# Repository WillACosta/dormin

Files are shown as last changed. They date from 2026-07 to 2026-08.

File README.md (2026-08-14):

## Dormin Split Keyboard

> 3×6 (+2 outer-pinky) Split Keyboard · 3 Thumb Keys · All 1U · MX Compatible

Dormin is a 42 — 36 keys split keyboard, inspired by some awesome keyboards that I've used and loved. The main goal is to create a customizable keyboard with optional features, but still as minimal as possible regarding the design.

### Must have specs

- Wireless Ble.
- Ultra low-profile build (<= 7mm).
- Low-profile switches and keycaps.
- Compatible with MX-Standard and the Gateron KS33/3.0 Low-Profile switches & Choc V2.
- Huge battery life (1200mAh).
- Minimalist and industrial design.
- Aluminum case and plate.
- 4 different layouts trough breakaway parts.
- Split and "Unibody" layouts (Using Pogo pins)
- MX-Spacing
- Status LEDs

**Optional**

- EC12 Rotatory Encoder
- SD OLED screen or Nice!View

## Layout Overview

The Dormin is a **40-key split keyboard** (20 keys per half) with a column-staggered matrix and a splayed thumb cluster.

| Zone | Columns | Rows | Keys/half | Notes |
|---|---|---|---|---|
| Matrix | 6 (outer → inner) | 3 (bottom, home, top) | 17 | Outer column skips bottom row (2 keys only) |
| Thumb | 3 (inner, home, outer) | 1 | 3 | Splayed arc, anchored below index |
| **Total** | | | **20** | **40 keys full board** |

### Column Stagger Profile

```
         outer  pinky  ring   middle  index  inner
stagger:   —    +u/2   +u/4   +u/4   −u/4   −u/4
mm:        0    +9.525 +4.763 +4.763 −4.763 −4.763
```

```
                    ┌──┐┌──┐
               ┌──┐ │  ││  │ ┌──┐
          ┌──┐ │  │ │Mi││Mi│ │  │ ┌──┐
     ┌──┐ │  │ │Ri││dd││dd│ │In│ │  │
     │  │ │Pi│ │ng││le││le│ │ne│ │  │
     │Ou│ │nk│ │  ││  ││  │ │r │ │  │
     │te│ │y │ │  ││  ││  │ │  │ │  │
     │r │ │  │ │  ││  ││  │ │  │ │  │
     └──┘ │  │ │  │└──┘└──┘ │  │ │  │
          └──┘ └──┘          └──┘ └──┘
                    ┌──┐
               ┌──┐│  │┌──┐
               │Th ││Th││Th│
               │ 3 ││ 2││ 1│
               └──┘└──┘└──┘
```

### Thumb Cluster Geometry

| Key | Splay | Spread | Stagger | Effective rotation |
|-----|---|---|---|---|
| thumb_inner | 0° | u (19.05mm) | 0mm | 0° |
| thumb_home | −15° | u+2.5 (21.55mm) | −2.7mm | −15° |
| thumb_outer | −14° | u+2.5 (21.55mm) | −2.5mm | −29° |

The thumb cluster anchors at `matrix_index_bottom` with a `[-0.1u, -1.30u]` offset, placing it slightly left and well below the index column — a natural resting position for the thumb.

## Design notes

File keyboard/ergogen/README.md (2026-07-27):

# Ergogen Layout Configuration

Ergogen is used to generate key switch positions, panel outlines, and KiCad PCB drafts.

## Generating Ergogen Files

To generate the PCB layout (`.kicad_pcb`) and outline assets using Ergogen:

1. **Run Ergogen CLI**:
   ```bash
   npx ergogen keyboard/ergogen -o keyboard/generated
   ```

2. **Generated Output (`keyboard/generated/`)**:
   - `keyboard/generated/pcbs/dormin.kicad_pcb`: Contains the KiCad PCB with switch footprints (`SW1` to `SW42`) using standard MX spacing and Edge.Cuts outlines.
   - `keyboard/generated/outlines/`: Contains DXF/SVG outline assets for switch plates and case panels.

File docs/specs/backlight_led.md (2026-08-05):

# Dormin Keyboard — White Backlight System

## Overview

Dormin uses a **single-zone white LED backlight** inspired by Apple's Magic Keyboard and MacBook keyboards. The objective is to provide a subtle, elegant, and battery-efficient backlight while keeping the hardware simple, inexpensive, and easy to manufacture using JLCPCB SMT Assembly.

Each keyboard half contains:

- One Seeed Studio XIAO nRF52840 Plus
- One AO3400A N-Channel MOSFET
- One warm white LED underneath each switch
- One current-limiting resistor per LED
- Dedicated LED power rail (`LED_VCC`)
- PWM brightness control

The entire backlight is controlled as a **single lighting zone**, allowing global brightness adjustment through PWM without requiring a dedicated LED driver.

### Why No LED Driver?

Dormin Rev. A intentionally avoids dedicated LED driver ICs (IS31FL37xx family).

Instead, all LEDs are switched simultaneously using a single PWM-controlled MOSFET.

#### Advantages

- Only one GPIO required
- Very small BOM
- Extremely simple schematic
- Easy PCB routing
- Excellent battery life
- Minimal firmware complexity
- Fully supported by ZMK PWM

#### Trade-offs

Supported:

- ✅ Backlight ON/OFF
- ✅ Global brightness control
- ✅ PWM dimming
- ✅ Fade in / Fade out
- ✅ Auto-off after inactivity

Not supported:

- ❌ Per-key brightness
- ❌ Reactive typing
- ❌ Ripple animations
- ❌ RGB effects
- ❌ Multiple lighting zones

# Power Architecture

Unlike the MCU and OLED, the backlight **does not use the XIAO's regulated 3.3 V output**.

Instead, the LEDs are powered directly from the battery.

Advantages:

- Lower regulator load
- Better battery efficiency
- Lower regulator temperature
- Higher available current
- Easier future expansion

The battery voltage is distributed into two independent branches:

- XIAO VBAT input
- LED_VCC (Backlight power rail)

---

# Electrical Architecture

```mermaid
flowchart LR

    BAT["LiPo Battery"]

    BRANCH((Power Junction))

    MCU["XIAO nRF52840 Plus"]

    PWM["LED_PWM GPIO"]

    RG["100R"]

    MOS["AO3400A<br/>N-MOSFET"]

    RPD["10K"]

    GND["GND"]

    CAP1["10uF"]
    CAP2["100nF"]

    subgraph BACKLIGHT["White Backlight"]

        R1["1K"]
        LED1["LED"]

        R2["1K"]
        LED2["LED"]

        RN["1K"]
        LEDN["LED ..."]

    end

    BAT --> BRANCH

    BRANCH --> MCU

    BRANCH --> LED_VCC["LED_VCC"]

    LED_VCC --> CAP1
    LED_VCC --> CAP2

    CAP1 --> GND
    CAP2 --> GND

    MCU --> PWM

    PWM --> RG

    RG --> MOS

    RPD --> GND
    RPD --> MOS

    LED_VCC --> R1 --> LED1 --> MOS
    LED_VCC --> R2 --> LED2 --> MOS
    LED_VCC --> RN --> LEDN --> MOS

    MOS --> GND
```

---

# Bill of Materials (BOM)

| Component | Value / Part Number | KiCad Symbol | KiCad Footprint | JLCPCB Assembly | Remarks | PCB / Schematic Notes |
|---|---|---|---|---|---|---|
| MCU | Seeed Studio XIAO nRF52840 Plus | `Seeed Studio XIAO nRF52840 Plus` *(Seeed official library)* | `Module:Seeed_XIAO_nRF52840_Plus` | ❌ Module | Main controller | One module per keyboard half |
| White LED | 0603 Warm White LED (≈4000–4500K) | `Device:LED` | `LED_SMD:LED_0603_1608Metric` | ✅ Yes | White backlight | One LED per switch |
| LED Current Limiting Resistor | **1K ±1%** | `Device:R` | `Resistor_SMD:R_0603_1608Metric` | ✅ Yes | Current limiting | One resistor per LED (VBAT-powered design) |
| Gate Resistor | **100R ±1%** | `Device:R` | `Resistor_SMD:R_0603_1608Metric` | ✅ Yes | Limits MOSFET gate charging current | Place close to MOSFET gate |
| Gate Pull-down Resistor | **10K ±1%** | `Device:R` | `Resistor_SMD:R_0603_1608Metric` | ✅ Yes | Keeps MOSFET OFF during boot | Gate → GND |
| MOSFET | AO3400A | `Device:Q_NMOS_GSD` | `Package_TO_SOT_SMD:SOT-23` | ✅ Yes | Low-side PWM switch | One per keyboard half |
| Bulk Capacitor | **10uF X5R/X7R ≥6.3V** | `Device:C` | `Capacitor_SMD:C_0603_1608Metric` *(0805 also acceptable)* | ✅ Yes | Bulk decoupling | Between `LED_VCC` and GND |
| High-Frequency Capacitor | **100nF X7R** | `Device:C` | `Capacitor_SMD:C_0603_1608Metric` | ✅ Yes | PWM noise filtering | Place next to the 10uF capacitor |
| Test Point *(Optional)* | Test Pad | `Connector:TestPoint` | `TestPoint:TestPoint_Pad_D1.0mm` | Optional | Debugging | Recommended for `LED_VCC` (optionally `LED_PWM`) |

---

# PCB Design Guidelines

## LED Placement

- One LED centered underneath each switch.
- Keep the LED as close as possible to the switch opening.
- Maintain consistent orientation across the PCB.

## MOSFET Placement

Place the AO3400A:

- Close to the XIAO module
- Close to the `LED_PWM` GPIO
- Close to the main `LED_SWITCH` return path

This minimizes PWM trace length and switching noise.

## Capacitor Placement

Place the **10uF** and **100nF** capacitors:

- Immediately after the `LED_VCC` power entry
- Close together
- Before the LED power distribution begins

## Power Routing

Recommended trace widths:

| Signal | Recommended Width |
|---|---:|
| BAT+ | 1.0 mm |
| LED_VCC | 0.5–1.0 mm |
| LED_SWITCH | 0.5–1.0 mm |
| LED_PWM | 0.20–0.25 mm |

---

# Firmware Features

Supported by the current hardware:

- Backlight ON/OFF
- Brightness adjustment
- PWM dimming
- Fade effects
- Auto-off after timeout
- Battery-saving modes

Future firmware may support:

- Ambient light sensor
- Automatic brightness
- Sleep fade animation

without requiring any hardware changes.

---

# Future Expansion

The current architecture intentionally leaves room for future revisions.

Possible upgrades include:

- Ferrite bead between `BAT+` and `LED_VCC`
- Current sensing
- Polyfuse protection
- Dedicated LED regulator
- I²C LED driver
- Multiple lighting zones

None of these upgrades require changing the LED placement or mechanical design.

---

# Final Design Summary

The Dormin backlight system prioritizes simplicity, efficiency, and longevity over visual effects.

The final architecture consists of:

- White-only backlight
- Single lighting zone
- PWM-controlled AO3400A MOSFET
- One resistor per LED
- LEDs powered directly from the battery (`VBAT`)
- Dedicated `LED_VCC` power rail
- 10uF + 100nF local decoupling
- No LED driver
- Fully compatible with ZMK
- Optimized for wireless battery-powered operation
- Easy to manufacture with JLCPCB SMT Assembly

This design closely follows the philosophy used in premium commercial keyboards: minimal hardware complexity, excellent battery life, and a clean, understated lighting experience.

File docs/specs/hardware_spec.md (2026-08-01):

## Hardware Definitions

This document describes the hardware decisions and choices for the Dormin Keyboard.

## Must Have

- Usage of "Panelized Non-Reversible" PCB (costs saving and easy routing).
- Seeed Studio XIAO nRF52840 Plus (20 GPIO).
- Optional components: OLED SSD1306 or Nice!View ; EC12 Rotatory Encoder.

## WIP

- RGB LEDs for status indicador ([WIP](./led_status_system.md)).
- Add tiny magnets on the side to "lock" the halves and use "unibody-like" (alternative to the pogo-pins).
- Add tiny magnets on the bottom to secure halves during transport and easy travel.

## Research

These are some ideas, but are not yet solid for implementation. Needs deep research.

- Pogo Pins support for charging the peripherel (while central is connected on power).
- NFC for wireless charging

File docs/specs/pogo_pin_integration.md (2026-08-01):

```mermaid
flowchart LR
    subgraph Left["Main / Left Keyboard Half - Schema v2 (Diode Added)"]
        L_XIAO["XIAO nRF52840"]
        L_BAT("LiPo Battery")
        L_DIODE["Schottky Diode (e.g. B5819WS)"]
        L_POGO["4-Pin Pogo Connector"]
        L_R1["330Ω Resistor"]
        L_R2["330Ω Resistor"]

        L_XIAO ---|BAT+| L_BAT
        L_XIAO ---|5V / VBUS| L_DIODE
        L_DIODE ---|Cathode → Pin 1| L_POGO
        L_XIAO ---|GND → Pin 2| L_POGO

        L_XIAO ---|GPIO TX| L_R1
        L_R1 ---|Pin 3| L_POGO

        L_XIAO ---|GPIO RX| L_R2
        L_R2 ---|Pin 4| L_POGO
    end

    subgraph Right["Peripheral / Right Keyboard Half"]
        R_POGO["4-Pad Target Contact"]
        R_XIAO["XIAO nRF52840"]
        R_BAT("LiPo Battery")
        R_R1["330Ω Resistor"]
        R_R2["330Ω Resistor"]

        R_POGO ---|Pad 1 → 5V / VBUS| R_XIAO
        R_POGO ---|Pad 2 → GND| R_XIAO

        R_POGO ---|Pad 3| R_R1
        R_R1 ---|GPIO TX| R_XIAO

        R_POGO ---|Pad 4| R_R2
        R_R2 ---|GPIO RX| R_XIAO

        R_XIAO ---|BAT+| R_BAT
    end

    L_POGO ===|Physical Magnetic Mating| R_POGO
```

```mermaid
flowchart LR

%% =====================================================================
%% LEFT HALF
%% =====================================================================

subgraph LEFT["Main / Left Half"]

    USB["USB_VBUS"]
    PF["Polyfuse (Optional)"]
    D["Schottky Diode"]
    TVS5L["5V TVS"]

    MCU_L["XIAO nRF52840 Plus"]
    BAT_L["LiPo Battery"]

    TVSD_L["2-Channel TVS"]
    R1["33Ω"]
    R2["33Ω"]

    POGO_L["4-Pin Pogo Connector"]

    BAT_L <-->|BAT+/BAT-| MCU_L

    USB --> PF
    PF --> D
    D --> POGO_L

    POGO_L --- TVS5L
    TVS5L --> GNDL["GND"]

    MCU_L --> R1
    R1 --> TVSD_L
    TVSD_L --> POGO_L

    MCU_L --> R2
    R2 --> TVSD_L

    MCU_L --- GNDL
    GNDL --> POGO_L

end

%% =====================================================================
%% RIGHT HALF
%% =====================================================================

subgraph RIGHT["Peripheral / Right Half"]

    POGO_R["4-Pin Target Pads"]

    TVS5R["5V TVS"]
    TVSD_R["2-Channel TVS"]

    R3["33Ω"]
    R4["33Ω"]

    MCU_R["XIAO nRF52840 Plus"]
    BAT_R["LiPo Battery"]

    GNDR["GND"]

    BAT_R <-->|BAT+/BAT-| MCU_R

    POGO_R --> MCU_R

    POGO_R --- TVS5R
    TVS5R --> GNDR

    POGO_R --> TVSD_R
    TVSD_R --> R3
    R3 --> MCU_R

    TVSD_R --> R4
    R4 --> MCU_R

    POGO_R --> GNDR
    MCU_R --- GNDR

end

%% =====================================================================
%% MECHANICAL CONNECTION
%% =====================================================================

POGO_L ===|"Magnetic Pogo Interface"| POGO_R
```

## BOM

| Function | Recommended Part | Package | KiCad Footprint | Placement Rule | Routing Rule | Notes |
| --- | --- | --- | --- | --- | --- | --- |
| **Magnetic Pogo Connector** | Xinyangze **YZP0048-20048-04025-03** _(or equivalent 4-pin connector)_ | Vendor-specific | **Custom footprint** | **On the PCB edge**, aligned with the enclosure and magnets. | Keep `POGO_VBUS`, `POGO_GND`, `POGO_LINK_IO1`, and `POGO_LINK_IO2` as short as practical leaving the connector. | Verify mechanical clearance using the STEP model before manufacturing. |
| **Reverse Current Protection** | **B5819WS** | SOD-323 / SOD-123W _(manufacturer dependent)_ | `Diode_SMD:D_SOD-323` or matching package | **Near the USB/XIAO power input**, **not** near the pogo connector. | Route `USB_VBUS → Polyfuse → Schottky → POGO_VBUS`. | Prevents power from the pogo connector or battery from backfeeding into the USB supply. |
| **Overcurrent Protection (Optional)** | Polyfuse ~500 mA Hold _(e.g. 0ZCJ0050AF2E)_ | 1206 | `Fuse:Fuse_1206_3216Metric` | Immediately after the USB power source. | Place before the Schottky diode. | Optional, but recommended for a premium design to protect against shorts on the pogo interface. |
| **VBUS ESD Protection** | **SMF5.0A** | DO-219AB (SMF) | `Diode_SMD:D_SMF` | **As close as possible to the pogo connector.** | Connect **directly between `POGO_VBUS` and `GND`**. Use a **very short trace** and **dedicated GND via** beside the device. | First line of defense against ESD and transient surges on the charging pin. |
| **GPIO ESD Protection** | **TPD2E2U06DCKR** | SC70-3 (DCK) | `Package_TO_SOT_SMD:SOT-353_SC-70-3` | **Immediately beside the pogo connector.** | Signal flow should be: **Pogo → TVS → 33 Ω → MCU**. Connect GND with a **dedicated via** next to the GND pin. | Protects the exposed communication lines (`POGO_LINK_IO1`, `POGO_LINK_IO2`) from ESD. |
| **Series Resistors** | **33 Ω ±1%** | 0402 or 0603 | `Resistor_SMD:R_0402_1005Metric` _(or 0603)_ | **Near the MCU**, not the connector. | One resistor per communication line, placed **after the TVS** and **before the MCU GPIO**. | Improves signal integrity and limits transient current into the MCU. |

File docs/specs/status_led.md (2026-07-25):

## LED status indicators spec

This document shortly explain the definitions for the LED status indicators for the Dormin keyboard. Here are some approaches that I found on the community.

## Requirements

- Minimalist and discret design: LEDs are invisible when off.
- 3 individual RGB lights (each side).
- **Statuses**: Bluetooth Profiles, Battery, and Split link.

## Addressable RGB LEDs using SK6812 Mini-E

- LED Strip:SK6812 addressable LEDs (1-4 LEDs recommended)
- Power: 5V preferred (3.3V compatible), appropriate current capacity
- Data Connection: Single GPIO pin connected to strip's DI (Data In)
- SPI Interface: Available SPI peripheral (uses MOSI pin for data)

> Addressable LED implementations here on [hitsmaxft/zmk-rgbled-widget](https://github.com/hitsmaxft/zmk-rgbled-widget#adding-support-in-custom-boardsshields).

### LED status behaviors

Minimalist and easy-to-remember colors (Nuphy inspired).

**Connection**

🔵🔵🔵 = [Solid] (Left) Host connected
🔵🔵🔵 = [Breathing] (Left) Host disconnected
🔵🔵🔵 = [Blinking] (Left) Advertising

🔵🔵🔵 = [Solid] (Right) Split Linked
🔵🔵🔵 = [Breathing] (Right) Split disconnected

⚪⚪⚪ = [Solid] (Left) USB connected

**Battery**

🟢🟢🟢 = [Solid] (Left/Right) 80 - 100%
🟡🟡⚫ = [Solid] (Left/Right) 40 - 79%
🔴⚫⚫ = [Solid] (Left/Right) < 40%

🟢🟢🟢 = [Breathing] (Left/Right) Charging

**Layers**

Base = None
Symbol = None
Number = None
Media = 🔵 (Cyan)
Dev = None
Extra = 🟣

LEDs are activated in two moments:

- On boot it shows connection state and battery level, a solid color for 2s then turn off;
- On demand by using specific combos;

When not in use they are turned off to energy saving purpose.

## ARGB and LP5012 LED Driver

The LP driver allows fully controlled RGB lights with the `SDA` and `SCL` GPIOs, using the I2C protocol, as it's shared it can run more than one peripheral on the same NET. The LP enable the following:

- Fully smooth controlled animations
- Ultra Low power
- Don't need dedicated GPIO (Same NET as screens)

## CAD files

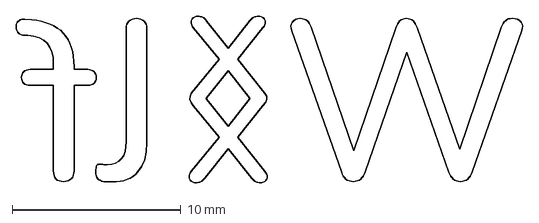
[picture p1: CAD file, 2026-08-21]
docs/assets/the_wolf_logo_full.dxf
30.1 x 9.87 mm

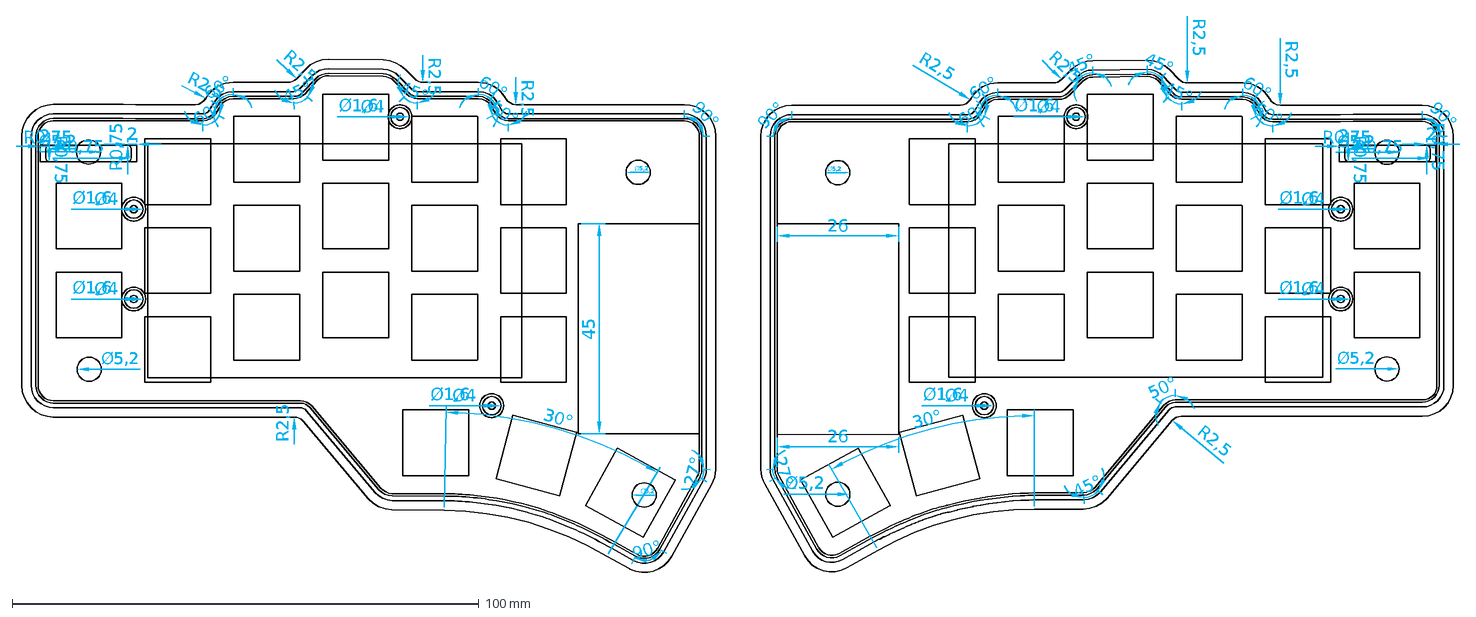
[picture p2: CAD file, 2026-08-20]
keyboard/case/projeccts/case_sketch.dxf
Ø5,2
45
2
26
R0,75
R2,5
Ø1,6
Ø4
27°
90°
45°
50°
60°
30°

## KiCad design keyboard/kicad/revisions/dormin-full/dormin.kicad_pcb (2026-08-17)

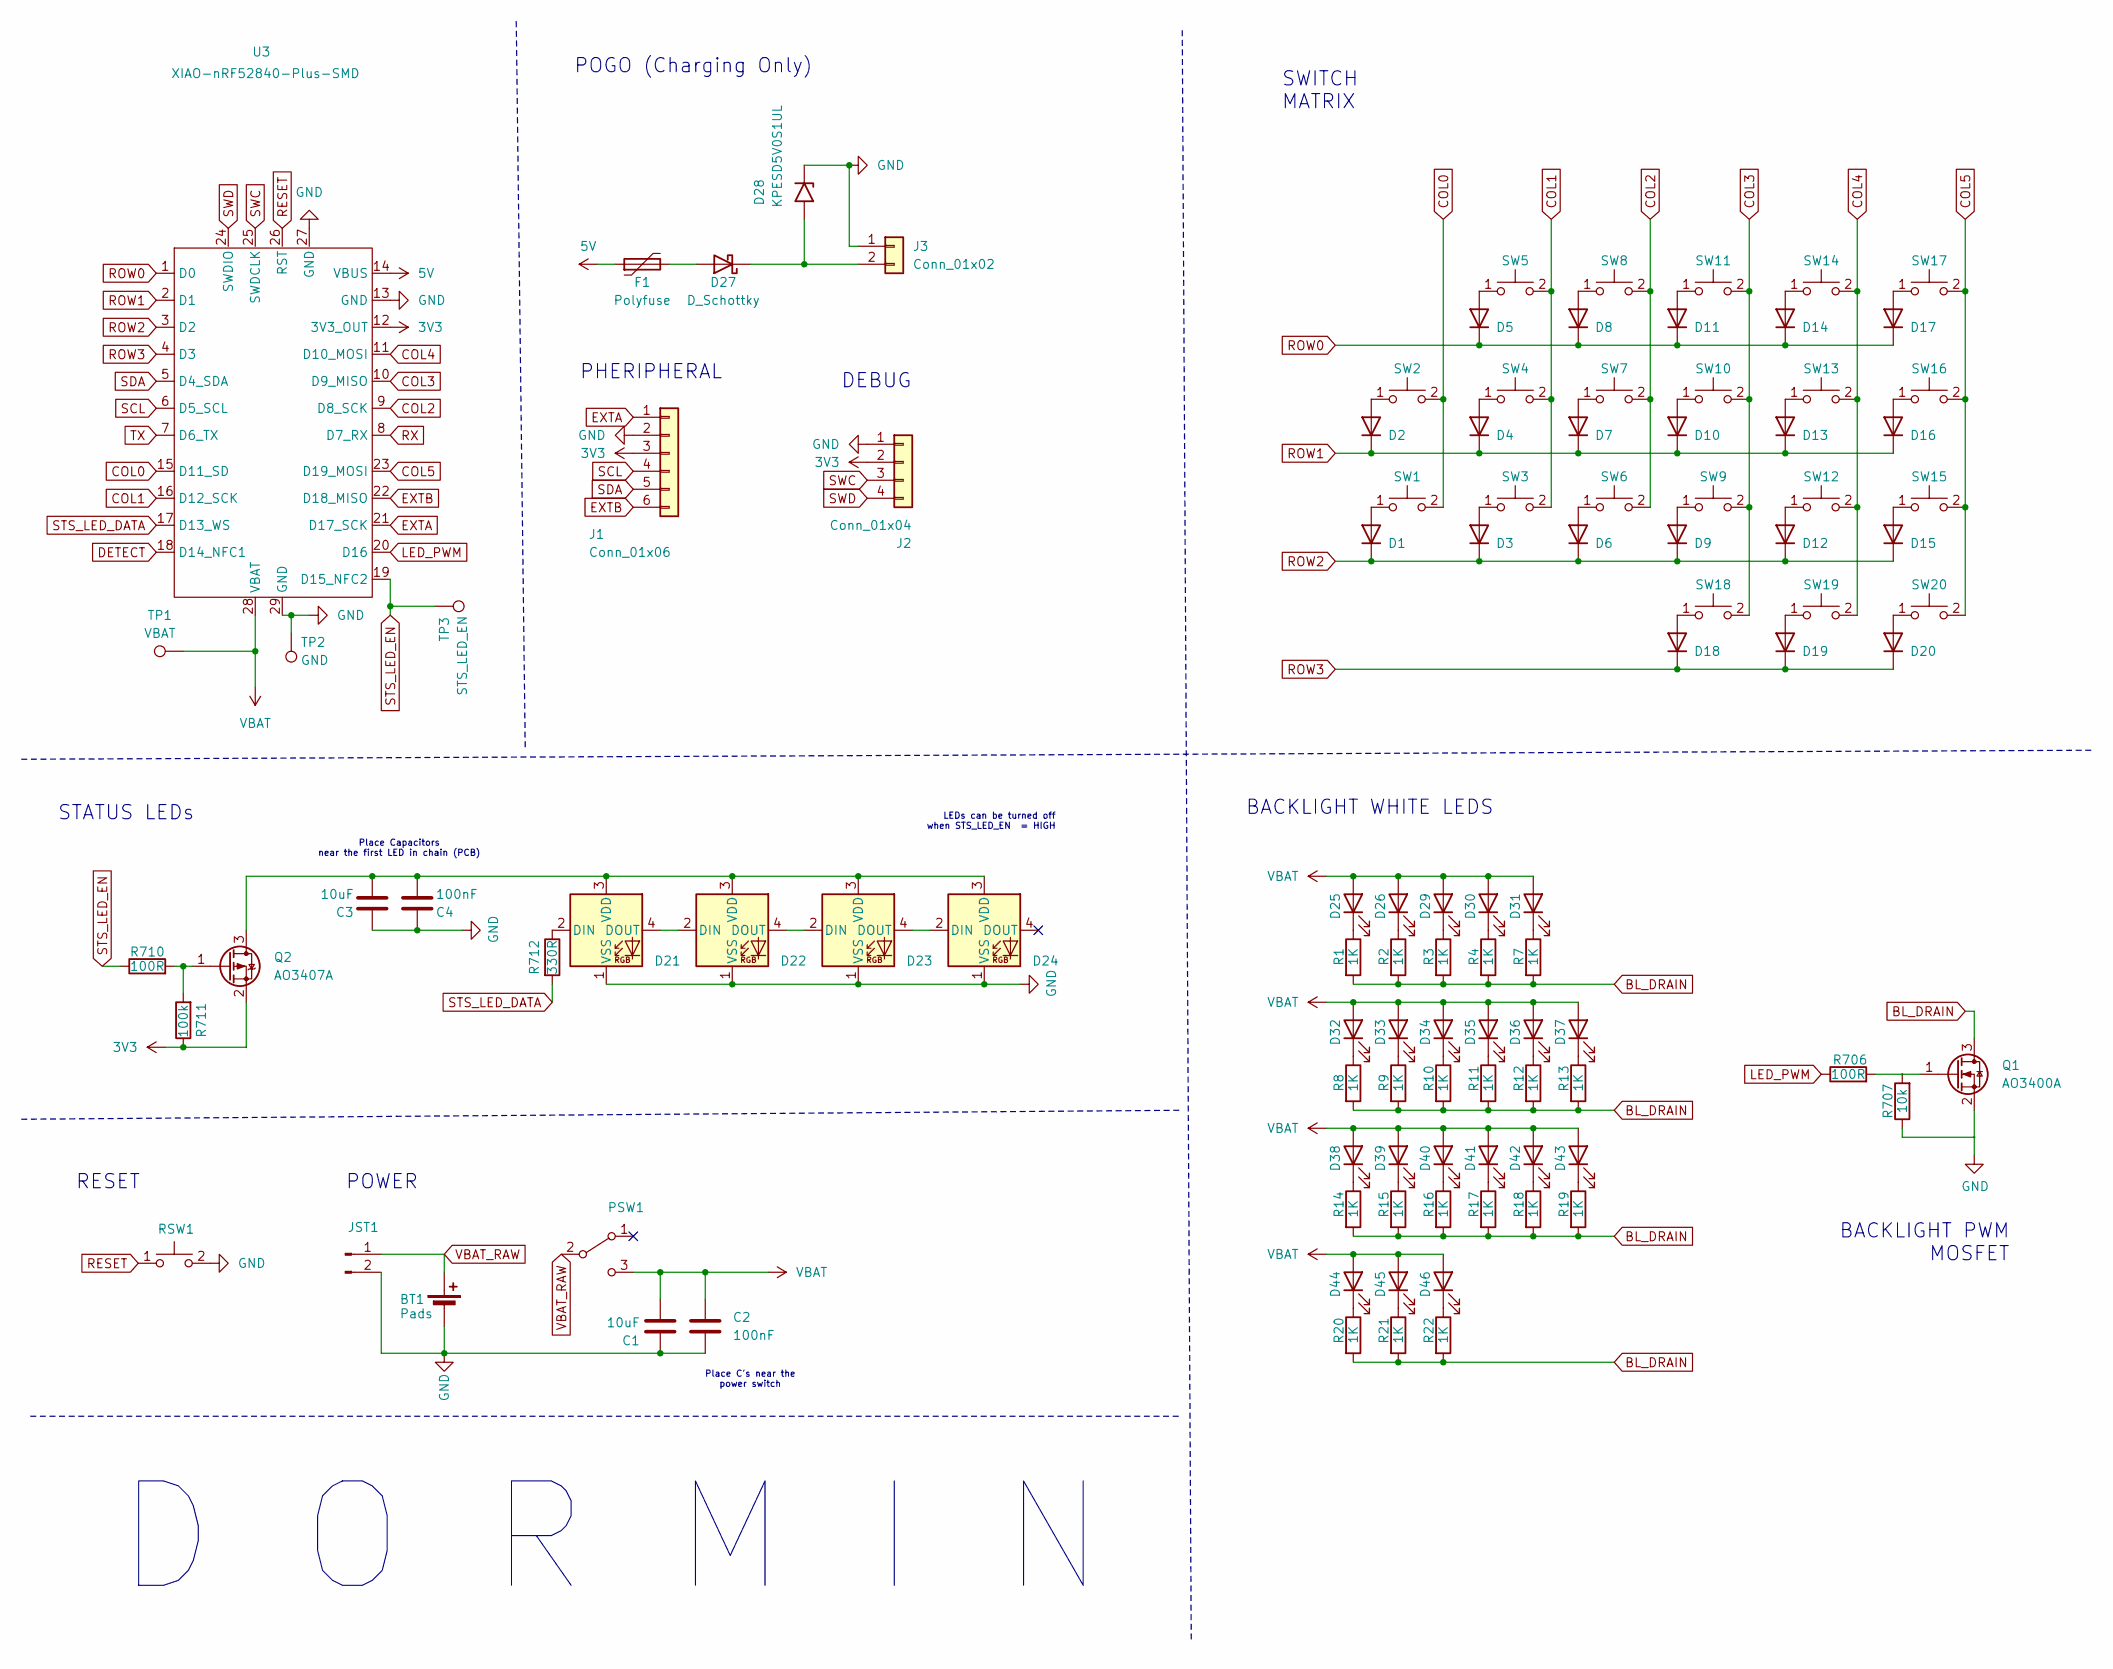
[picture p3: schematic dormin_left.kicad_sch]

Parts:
BT1: Pads; Battery_Pad
C1, C3: 10uF; C_0603_1608Metric
C2, C4: 100nF; C_0603_1608Metric
D1, D2, D3, D4, D5, D6, D7, D8, D9, D10, D11, D12, D13, D14, D15, D16, D17, D18, D19, D20: 1N4148W; D_SOD-123
D21, D22, D23, D24: SK6812MINI-E; LED_SK6812MINI-E_3.2x2.8mm_P1.5mm_ReverseMount
D25, D26, D29, D30, D31, D32, D33, D34, D35, D36, D37, D38, D39, D40, D41, D42, D43, D44, D45, D46: LED; LED_MHT151WDT
D27: D_Schottky; D_SOD-523
D28: KPESD5V0S1UL; D_SOD-882
F1: Polyfuse; Fuse_1206_3216Metric
J1: Conn_01x06; SMD_Conn_1x06_P2.54mm_Vertical
J2: Conn_01x04; PinSocket_1x04_P2.54mm_Vertical
J3: Conn_01x02; Pogo1x2-Right-Angle
JST1: Conn_01x02_Pin; JST_GH_SM02B-GHS-TB_1x02-1MP_P1.25mm_Horizontal
PSW1: SW_SPDT; SW_MSK12C02-HB
Q1: AO3400A; SOT-23
Q2: AO3407A; SOT-23; MPN AO3407A
R1, R2, R3, R4, R7, R8, R9, R10, R11, R12, R13, R14, R15, R16, R17, R18, R19, R20, R21, R22: 1K; R_0603_1608Metric
R706, R710: 100R; R_0603_1608Metric
R707: 10k; R_0603_1608Metric
R711: 100k; R_0603_1608Metric
R712: 330R; R_0603_1608Metric
RSW1: RSW1; SW_SPST_SKQG_WithStem
SW1, SW2, SW3, SW4, SW5, SW6, SW7, SW8, SW9, SW10, SW11, SW12, SW13, SW14, SW15, SW16, SW17, SW18, SW19, SW20: SW_Push; NF_LED_1206_SW_KS33_3_0_HS_1U
TP1: VBAT; TestPoint_Pad_D1.0mm
TP2: GND; TestPoint_Pad_D1.0mm
TP3: STS_LED_EN; TestPoint_Pad_D1.0mm
U3: XIAO-nRF52840-Plus-SMD

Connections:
3V3: J1.3, J2.2, Q2.2 (S), R711.1, U3.12 (3V3_OUT)
5V: F1.1, U3.14 (VBUS)
BL_DRAIN: Q1.3 (D), R1.2, R2.2, R3.2, R4.2, R7.2, R8.2, R9.2, R10.2, R11.2, R12.2, R13.2, R14.2, R15.2, R16.2, R17.2, R18.2, R19.2, R20.2, R21.2, R22.2
COL0: SW1.2, SW2.2, U3.15 (D11_SD)
COL1: SW3.2, SW4.2, SW5.2, U3.16 (D12_SCK)
COL2: SW6.2, SW7.2, SW8.2, U3.9 (D8_SCK)
COL3: SW9.2, SW10.2, SW11.2, SW18.2, U3.10 (D9_MISO)
COL4: SW12.2, SW13.2, SW14.2, SW19.2, U3.11 (D10_MOSI)
COL5: SW15.2, SW16.2, SW17.2, SW20.2, U3.23 (D19_MOSI)
DETECT: U3.18 (D14_NFC1)
EXTA: J1.1, U3.21 (D17_SCK)
EXTB: J1.6, U3.22 (D18_MISO)
GND: BT1.2 (-), C1.2, C2.2, C3.1, C4.2, D21.1 (VSS), D22.1 (VSS), D23.1 (VSS), D24.1 (VSS), D28.1 (A1), J1.2, J2.1, J3.1, JST1.2, Q1.2 (S), R707.1, RSW1.2, TP2.1 (1_1), U3.13 (GND), U3.27 (GND), U3.29 (GND)
LED_PWM: R706.1, U3.20 (D16)
unnamed: D1.2 (A), SW1.1
unnamed: D2.2 (A), SW2.1
unnamed: D3.2 (A), SW3.1
unnamed: D4.2 (A), SW4.1
unnamed: D5.2 (A), SW5.1
unnamed: D6.2 (A), SW6.1
unnamed: D7.2 (A), SW7.1
unnamed: D8.2 (A), SW8.1
unnamed: D9.2 (A), SW9.1
unnamed: D10.2 (A), SW10.1
unnamed: D11.2 (A), SW11.1
unnamed: D12.2 (A), SW12.1
unnamed: D13.2 (A), SW13.1
unnamed: D14.2 (A), SW14.1
unnamed: D15.2 (A), SW15.1
unnamed: D16.2 (A), SW16.1
unnamed: D17.2 (A), SW17.1
unnamed: D18.2 (A), SW18.1
unnamed: D19.2 (A), SW19.1
unnamed: D20.2 (A), SW20.1
unnamed: D21.2 (DIN), R712.1
unnamed: D21.4 (DOUT), D22.2 (DIN)
unnamed: C3.2, C4.1, D21.3 (VDD), D22.3 (VDD), D23.3 (VDD), D24.3 (VDD), Q2.3 (D)
unnamed: D22.4 (DOUT), D23.2 (DIN)
unnamed: D23.4 (DOUT), D24.2 (DIN)
unnamed: D25.1 (K), R1.1
unnamed: D26.1 (K), R2.1
unnamed: D27.2 (A), F1.2
unnamed: D27.1 (K), D28.2 (A2), J3.2
unnamed: D29.1 (K), R3.1
unnamed: D30.1 (K), R4.1
unnamed: D31.1 (K), R7.1
unnamed: D32.1 (K), R8.1
unnamed: D33.1 (K), R9.1
unnamed: D34.1 (K), R10.1
unnamed: D35.1 (K), R11.1
unnamed: D36.1 (K), R12.1
unnamed: D37.1 (K), R13.1
unnamed: D38.1 (K), R14.1
unnamed: D39.1 (K), R15.1
unnamed: D40.1 (K), R16.1
unnamed: D41.1 (K), R17.1
unnamed: D42.1 (K), R18.1
unnamed: D43.1 (K), R19.1
unnamed: D44.1 (K), R20.1
unnamed: D45.1 (K), R21.1
unnamed: D46.1 (K), R22.1
unnamed: Q1.1 (G), R706.2, R707.2
unnamed: Q2.1 (G), R710.2, R711.2
RESET: RSW1.1, U3.26 (RST)
ROW0: D5.1 (K), D8.1 (K), D11.1 (K), D14.1 (K), D17.1 (K), U3.1 (D0)
ROW1: D2.1 (K), D4.1 (K), D7.1 (K), D10.1 (K), D13.1 (K), D16.1 (K), U3.2 (D1)
ROW2: D1.1 (K), D3.1 (K), D6.1 (K), D9.1 (K), D12.1 (K), D15.1 (K), U3.3 (D2)
ROW3: D18.1 (K), D19.1 (K), D20.1 (K), U3.4 (D3)
RX: U3.8 (D7_RX)
SCL: J1.4, U3.6 (D5_SCL)
SDA: J1.5, U3.5 (D4_SDA)
STS_LED_DATA: R712.2, U3.17 (D13_WS)
STS_LED_EN: R710.1, TP3.1 (1_1), U3.19 (D15_NFC2)
SWC: J2.3, U3.25 (SWDCLK)
SWD: J2.4, U3.24 (SWDIO)
TX: U3.7 (D6_TX)
VBAT: C1.1, C2.1, D25.2 (A), D26.2 (A), D29.2 (A), D30.2 (A), D31.2 (A), D32.2 (A), D33.2 (A), D34.2 (A), D35.2 (A), D36.2 (A), D37.2 (A), D38.2 (A), D39.2 (A), D40.2 (A), D41.2 (A), D42.2 (A), D43.2 (A), D44.2 (A), D45.2 (A), D46.2 (A), PSW1.3 (C), TP1.1 (1_1), U3.28 (VBAT)
VBAT_RAW: BT1.1 (+), JST1.1, PSW1.2 (B)

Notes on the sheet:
DEBUG
LEDs can be turned off when STS_LED_EN = HIGH
RESET
Place C's near the power switch
Place Capacitors near the first LED in chain (PCB)
BACKLIGHT PWM MOSFET
POWER
D O R M I N
STATUS LEDs
BACKLIGHT WHITE LEDS
SWITCH MATRIX
PHERIPHERAL
POGO (Charging Only)

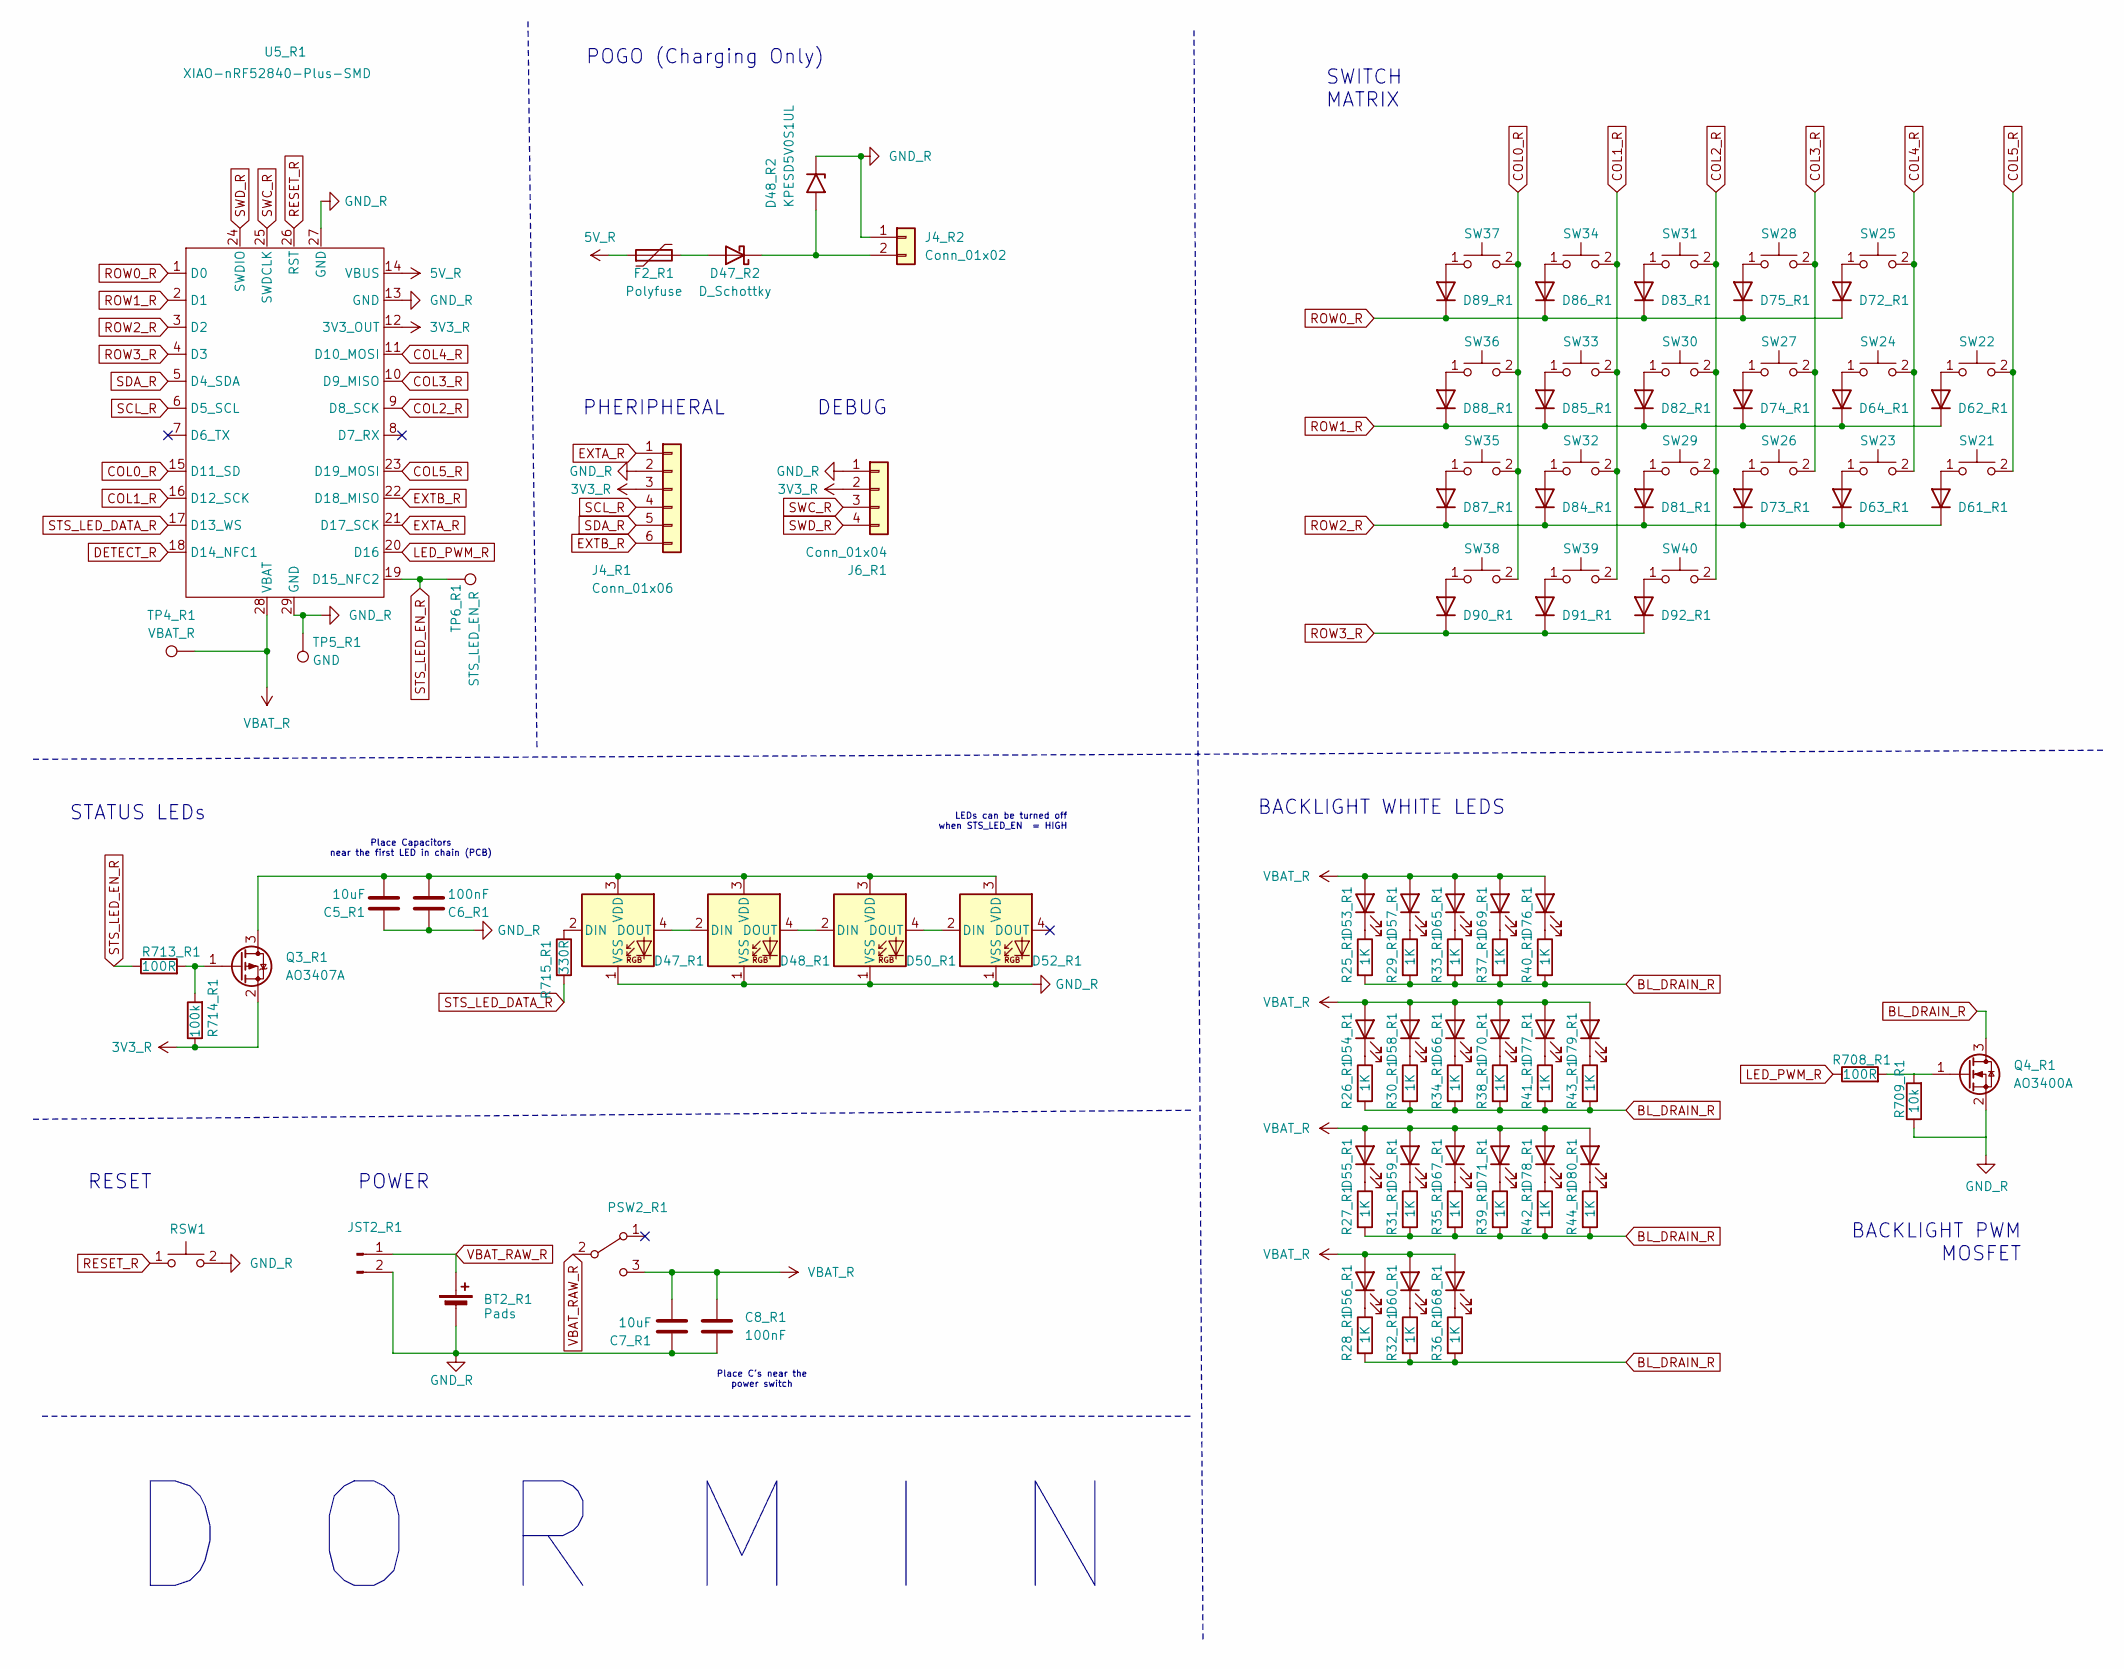
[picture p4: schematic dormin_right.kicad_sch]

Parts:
3V3_R01, 3V3_R02, 3V3_R03, 3V3_R04: 3V3_R
5V_R02: 5V_R
BT2_R1: Pads; Battery_Pad
C5_R1, C7_R1: 10uF; C_0603_1608Metric
C6_R1, C8_R1: 100nF; C_0603_1608Metric
D47_R1, D48_R1, D50_R1, D52_R1: SK6812MINI-E; LED_SK6812MINI-E_3.2x2.8mm_P1.5mm_ReverseMount
D47_R2: D_Schottky; D_SOD-523
D48_R2: KPESD5V0S1UL; D_SOD-882
D53_R1, D54_R1, D55_R1, D56_R1, D57_R1, D58_R1, D59_R1, D60_R1, D65_R1, D66_R1, D67_R1, D68_R1, D69_R1, D70_R1, D71_R1, D76_R1, D77_R1, D78_R1, D79_R1, D80_R1: LED; LED_MHT151WDT
D61_R1, D62_R1, D63_R1, D64_R1, D72_R1, D73_R1, D74_R1, D75_R1, D81_R1, D82_R1, D83_R1, D84_R1, D85_R1, D86_R1, D87_R1, D88_R1, D89_R1, D90_R1, D91_R1, D92_R1: 1N4148W; D_SOD-123
F2_R1: Polyfuse; Fuse_1206_3216Metric
GND_R03, GND_R04, GND_R05, GND_R06, GND_R07, GND_R08, GND_R09: GND_R
J4_R1: Conn_01x06; SMD_Conn_1x06_P2.54mm_Vertical
J4_R2: Conn_01x02; Pogo1x2-Right-Angle
J6_R1: Conn_01x04; PinSocket_1x04_P2.54mm_Vertical
JST2_R1: Conn_01x02_Pin; JST_GH_SM02B-GHS-TB_1x02-1MP_P1.25mm_Horizontal
PSW2_R1: SW_SPDT; SW_MSK12C02-HB
Q3_R1: AO3407A; SOT-23; MPN AO3407A
Q4_R1: AO3400A; SOT-23
R25_R1, R26_R1, R27_R1, R28_R1, R29_R1, R30_R1, R31_R1, R32_R1, R33_R1, R34_R1, R35_R1, R36_R1, R37_R1, R38_R1, R39_R1, R40_R1, R41_R1, R42_R1, R43_R1, R44_R1: 1K; R_0603_1608Metric
R708_R1, R713_R1: 100R; R_0603_1608Metric
R709_R1: 10k; R_0603_1608Metric
R714_R1: 100k; R_0603_1608Metric
R715_R1: 330R; R_0603_1608Metric
RSW2_R1: RSW1; SW_SPST_SKQG_WithStem
SW21, SW22, SW23, SW24, SW25, SW26, SW27, SW28, SW29, SW30, SW31, SW32, SW33, SW34, SW35, SW36, SW37, SW38, SW39, SW40: SW_Push; NF_LED_1206_SW_KS33_3_0_HS_1U
TP4_R1: VBAT_R; TestPoint_Pad_D1.0mm
TP5_R1: GND; TestPoint_Pad_D1.0mm
TP6_R1: STS_LED_EN_R; TestPoint_Pad_D1.0mm
U5_R1: XIAO-nRF52840-Plus-SMD
VBAT_R01: VBAT_R

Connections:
5V_R: 5V_R02.1, F2_R1.1, U5_R1.14 (VBUS)
BL_DRAIN_R: Q4_R1.3 (D), R25_R1.2, R26_R1.2, R27_R1.2, R28_R1.2, R29_R1.2, R30_R1.2, R31_R1.2, R32_R1.2, R33_R1.2, R34_R1.2, R35_R1.2, R36_R1.2, R37_R1.2, R38_R1.2, R39_R1.2, R40_R1.2, R41_R1.2, R42_R1.2, R43_R1.2, R44_R1.2
COL0_R: SW35.2, SW36.2, SW37.2, SW38.2, U5_R1.15 (D11_SD)
COL1_R: SW32.2, SW33.2, SW34.2, SW39.2, U5_R1.16 (D12_SCK)
COL2_R: SW29.2, SW30.2, SW31.2, SW40.2, U5_R1.9 (D8_SCK)
COL3_R: SW26.2, SW27.2, SW28.2, U5_R1.10 (D9_MISO)
COL4_R: SW23.2, SW24.2, SW25.2, U5_R1.11 (D10_MOSI)
COL5_R: SW21.2, SW22.2, U5_R1.23 (D19_MOSI)
DETECT_R: U5_R1.18 (D14_NFC1)
EXTA_R: J4_R1.1, U5_R1.21 (D17_SCK)
EXTB_R: J4_R1.6, U5_R1.22 (D18_MISO)
LED_PWM_R: R708_R1.1, U5_R1.20 (D16)
unnamed: D47_R1.2 (DIN), R715_R1.1
unnamed: D47_R1.4 (DOUT), D48_R1.2 (DIN)
unnamed: C5_R1.2, C6_R1.1, D47_R1.3 (VDD), D48_R1.3 (VDD), D50_R1.3 (VDD), D52_R1.3 (VDD), Q3_R1.3 (D)
unnamed: D47_R2.2 (A), F2_R1.2
unnamed: D47_R2.1 (K), D48_R2.2 (A2), J4_R2.2
unnamed: D48_R1.4 (DOUT), D50_R1.2 (DIN)
unnamed: D50_R1.4 (DOUT), D52_R1.2 (DIN)
unnamed: D53_R1.1 (K), R25_R1.1
unnamed: D54_R1.1 (K), R26_R1.1
unnamed: D55_R1.1 (K), R27_R1.1
unnamed: D56_R1.1 (K), R28_R1.1
unnamed: D57_R1.1 (K), R29_R1.1
unnamed: D58_R1.1 (K), R30_R1.1
unnamed: D59_R1.1 (K), R31_R1.1
unnamed: D60_R1.1 (K), R32_R1.1
unnamed: D61_R1.2 (A), SW21.1
unnamed: D62_R1.2 (A), SW22.1
unnamed: D63_R1.2 (A), SW23.1
unnamed: D64_R1.2 (A), SW24.1
unnamed: D65_R1.1 (K), R33_R1.1
unnamed: D66_R1.1 (K), R34_R1.1
unnamed: D67_R1.1 (K), R35_R1.1
unnamed: D68_R1.1 (K), R36_R1.1
unnamed: D69_R1.1 (K), R37_R1.1
unnamed: D70_R1.1 (K), R38_R1.1
unnamed: D71_R1.1 (K), R39_R1.1
unnamed: D72_R1.2 (A), SW25.1
unnamed: D73_R1.2 (A), SW26.1
unnamed: D74_R1.2 (A), SW27.1
unnamed: D75_R1.2 (A), SW28.1
unnamed: D76_R1.1 (K), R40_R1.1
unnamed: D77_R1.1 (K), R41_R1.1
unnamed: D78_R1.1 (K), R42_R1.1
unnamed: D79_R1.1 (K), R43_R1.1
unnamed: D80_R1.1 (K), R44_R1.1
unnamed: D81_R1.2 (A), SW29.1
unnamed: D82_R1.2 (A), SW30.1
unnamed: D83_R1.2 (A), SW31.1
unnamed: D84_R1.2 (A), SW32.1
unnamed: D85_R1.2 (A), SW33.1
unnamed: D86_R1.2 (A), SW34.1
unnamed: D87_R1.2 (A), SW35.1
unnamed: D88_R1.2 (A), SW36.1
unnamed: D89_R1.2 (A), SW37.1
unnamed: D90_R1.2 (A), SW38.1
unnamed: D91_R1.2 (A), SW39.1
unnamed: D92_R1.2 (A), SW40.1
unnamed: Q3_R1.1 (G), R713_R1.2, R714_R1.2
unnamed: Q4_R1.1 (G), R708_R1.2, R709_R1.2
RESET_R: RSW2_R1.1, U5_R1.26 (RST)
ROW0_R: D72_R1.1 (K), D75_R1.1 (K), D83_R1.1 (K), D86_R1.1 (K), D89_R1.1 (K), U5_R1.1 (D0)
ROW1_R: D62_R1.1 (K), D64_R1.1 (K), D74_R1.1 (K), D82_R1.1 (K), D85_R1.1 (K), D88_R1.1 (K), U5_R1.2 (D1)
ROW2_R: D61_R1.1 (K), D63_R1.1 (K), D73_R1.1 (K), D81_R1.1 (K), D84_R1.1 (K), D87_R1.1 (K), U5_R1.3 (D2)
ROW3_R: D90_R1.1 (K), D91_R1.1 (K), D92_R1.1 (K), U5_R1.4 (D3)
SCL_R: J4_R1.4, U5_R1.6 (D5_SCL)
SDA_R: J4_R1.5, U5_R1.5 (D4_SDA)
STS_LED_DATA_R: R715_R1.2, U5_R1.17 (D13_WS)
STS_LED_EN_R: R713_R1.1, TP6_R1.1 (1_1), U5_R1.19 (D15_NFC2)
SWC_R: J6_R1.3, U5_R1.25 (SWDCLK)
SWD_R: J6_R1.4, U5_R1.24 (SWDIO)
VBAT_RAW_R: BT2_R1.1 (+), JST2_R1.1, PSW2_R1.2 (B)

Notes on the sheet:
STATUS LEDs
SWITCH MATRIX
Place C's near the power switch
D O R M I N
RESET
BACKLIGHT PWM MOSFET
LEDs can be turned off when STS_LED_EN = HIGH
DEBUG
Place Capacitors near the first LED in chain (PCB)
BACKLIGHT WHITE LEDS
PHERIPHERAL
POGO (Charging Only)
POWER

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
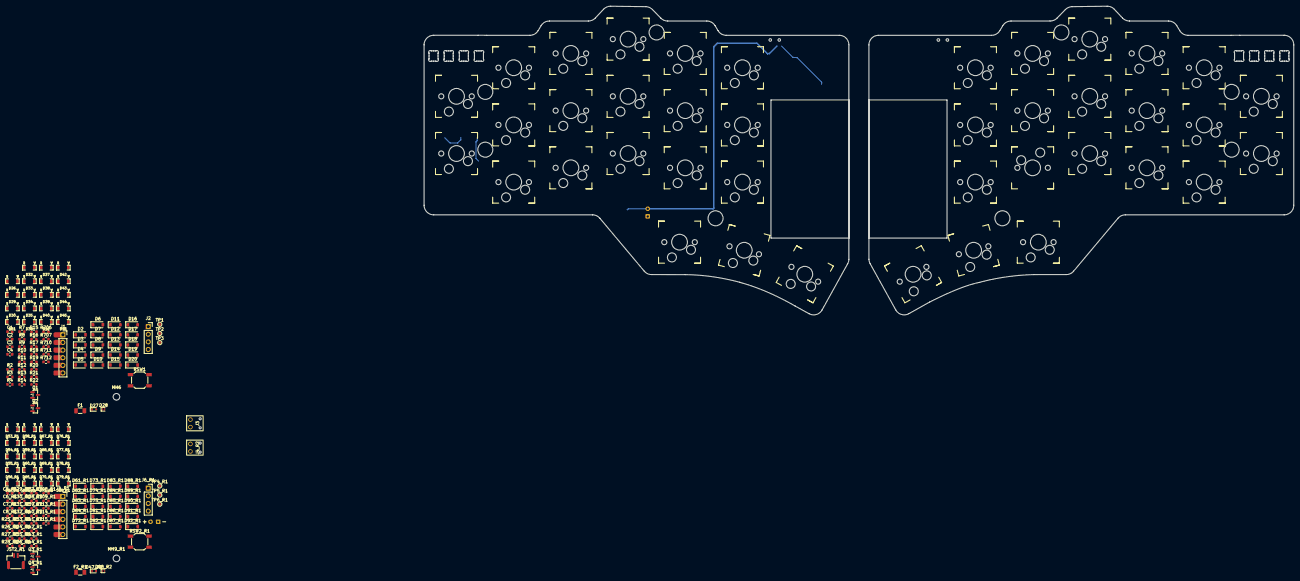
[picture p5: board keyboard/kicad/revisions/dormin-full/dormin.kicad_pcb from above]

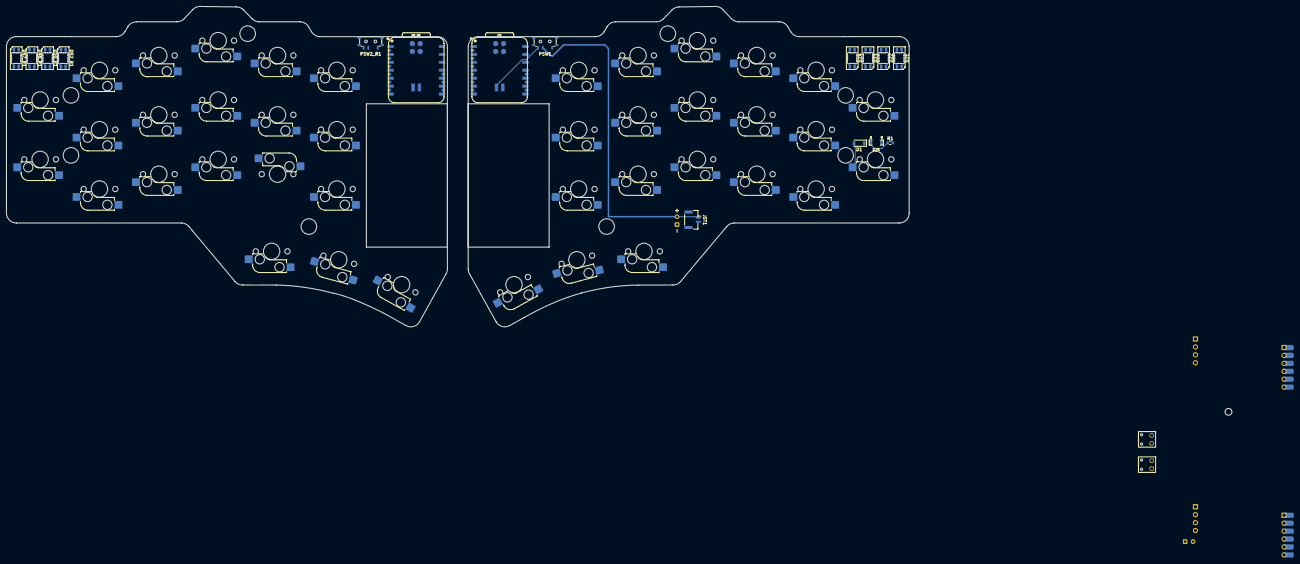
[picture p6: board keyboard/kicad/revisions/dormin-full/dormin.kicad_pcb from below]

Board: 2 copper layers, 220 parts (17 on the bottom side), 150 nets.

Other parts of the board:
MH6, MH9_R1: MountingHole_2.2mm_M2

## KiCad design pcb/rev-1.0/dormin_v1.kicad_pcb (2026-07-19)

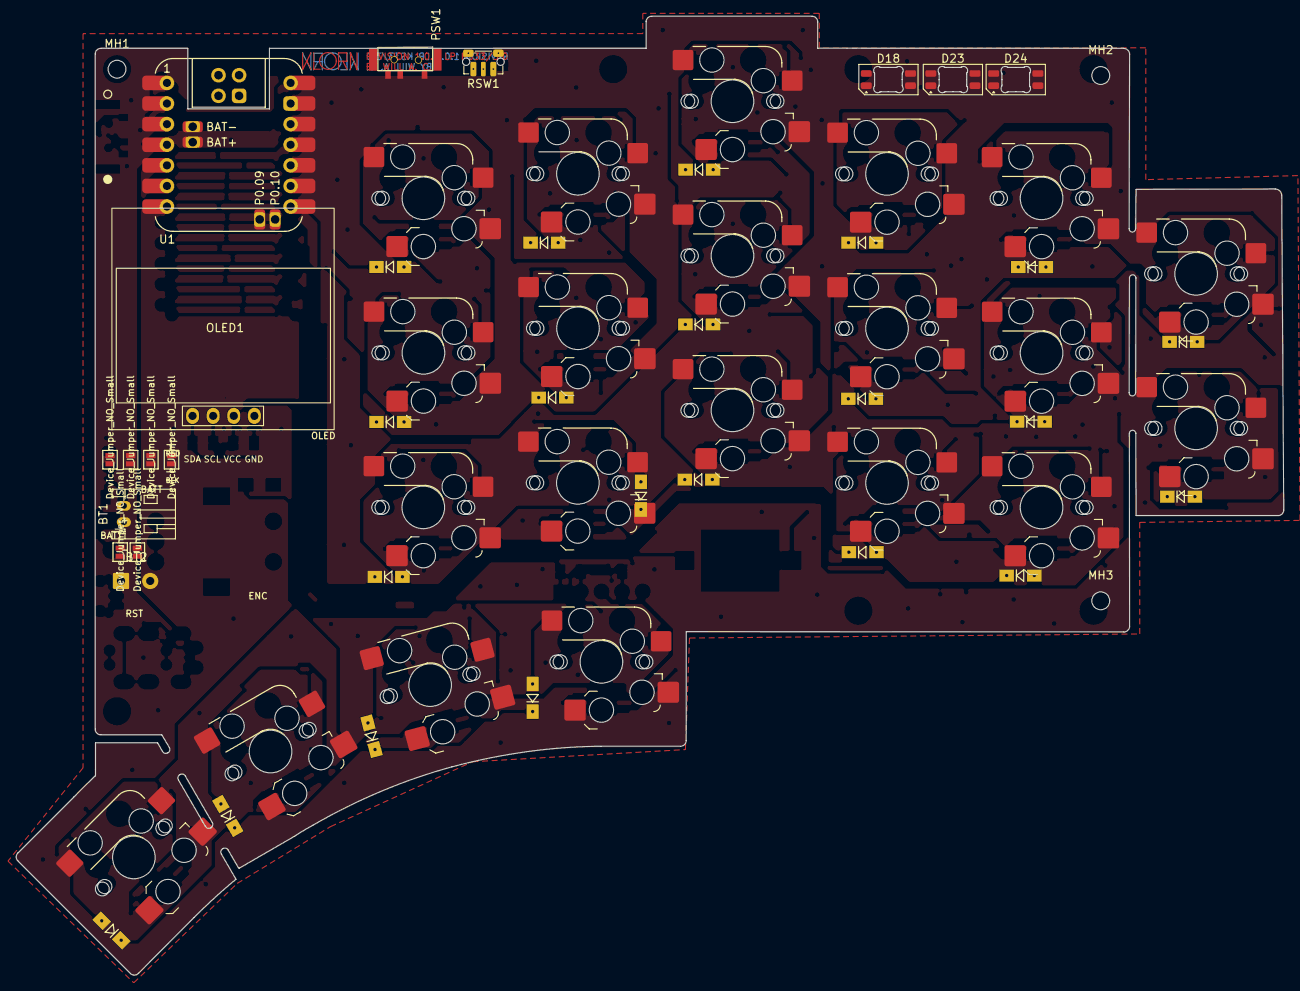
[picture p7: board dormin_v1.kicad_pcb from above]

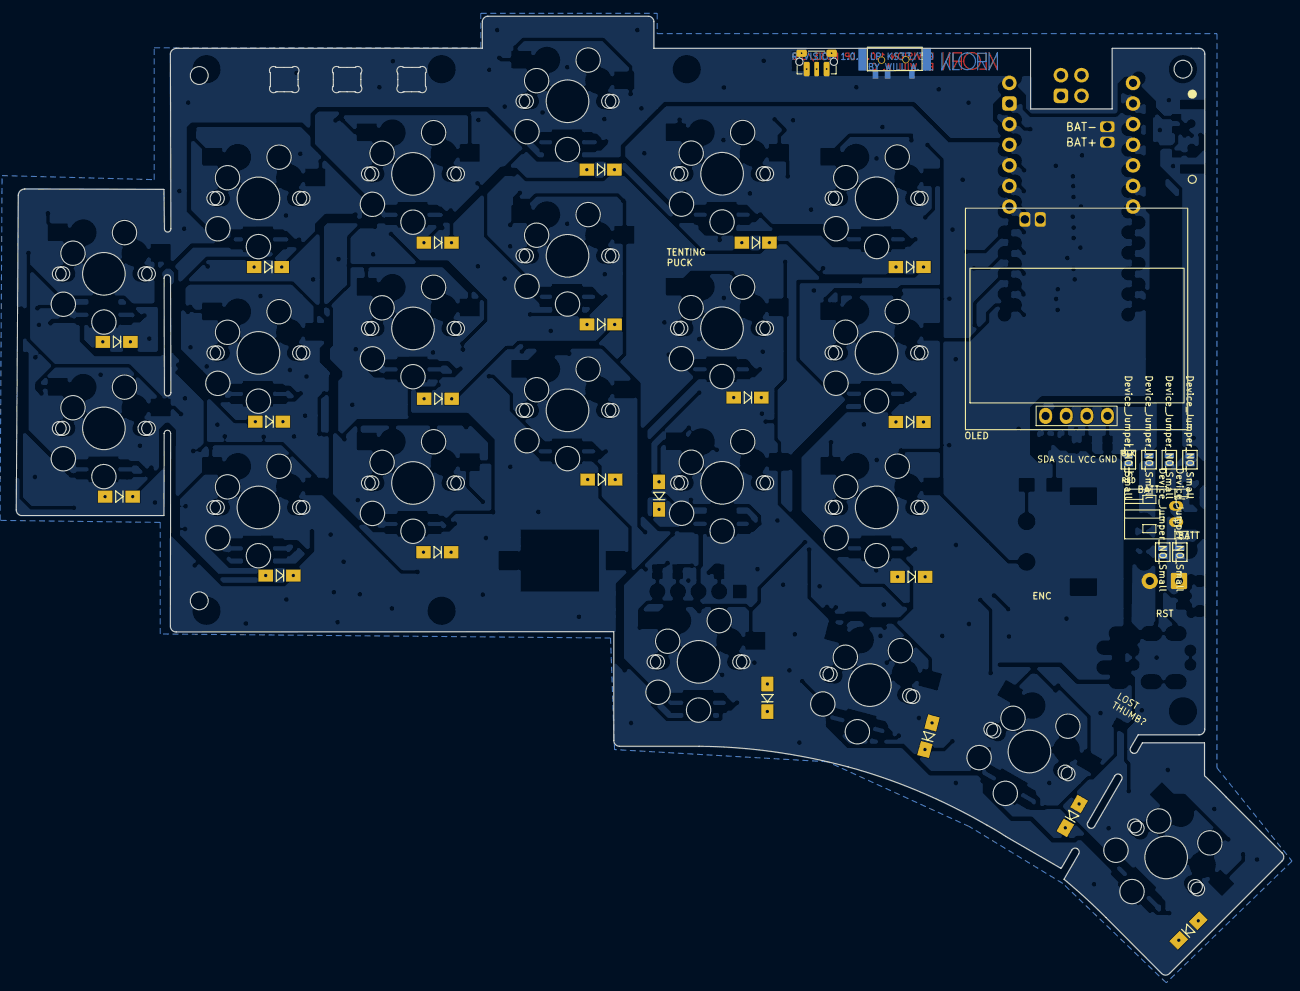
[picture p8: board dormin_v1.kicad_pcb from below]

Board: 2 copper layers, 156.2 x 118.2 mm, 68 parts (6 on the bottom side), 19 nets, no tracks yet.

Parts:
BT1: JST Connector; JST_PH_reversible
BT2: Battery_Cell; custombatteryconnector_small
D1, D2, D3, D4, D5, D6, D7, D8, D9, D10, D11, D12, D13, D14, D15, D16, D17, D19, D20, D21, D22: D_Small; Diode_SOD123
D18, D23, D24: SK6812MINI-E; LED_SK6812MINI-E_3.2x2.8mm_P1.5mm_ReverseMount
JP1, JP2, JP3, JP4, JP5, JP6, JP7, JP8, JP22, JP23, JP24, JP25: Device_Jumper_NO_Small; Jumper
MH1, MH2, MH3, MH4, MH5: MountingHole_2.2mm_M2
OLED1: SSD1306; SSD1306_128x64OLED
PSW1: SW_DPDT_x2; MSK12C02_reversible
RSW1: SW_Push; SW_Push_1P1T-MP_NO_Horizontal_Alps_SKRTLAE010_both_sides
SW1, SW2, SW3, SW4, SW5, SW6, SW7, SW8, SW9, SW10, SW11, SW12, SW13, SW14, SW15, SW16, SW17, SW19, SW20, SW21, SW22: SW_PUSH-MX_CHOC; SW_MXchoc_HS_1u
U1: Seeeduino Xiao nRF52840; Xiao_nRF52840_ACH

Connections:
/BAT-: BT1.2 (-), JP24.1, JP25.1
/PSW: BT2.1 (+), JP23.2, JP24.2, PSW1.2 (B)
BAT+: BT1.1 (+), JP22.1, JP23.1, U1.16 (BAT+)
GND: BT2.2 (-), D18.1 (VSS), D23.1 (VSS), D24.1 (VSS), JP1.2, JP8.2, JP22.2, JP25.2, RSW1.1, U1.9 (GND), U1.15 (BAT-), U1.22 (GND)
LED: D18.2 (DIN), U1.18 (P0.10)
unnamed: D18.4 (DOUT), D23.2 (DIN)
unnamed: D23.4 (DOUT), D24.2 (DIN)
unnamed: JP1.1, JP5.1, OLED1.1 (GND)
unnamed: JP3.1, JP7.1, OLED1.3 (SCL)
unnamed: JP4.1, JP8.1, OLED1.4 (SDA)
unnamed: JP2.1, JP6.1, OLED1.2 (VCC)
RESET: RSW1.2, U1.21 (RST)
SCL: JP3.2, JP6.2, U1.6 (P0.05)
SDA: JP4.2, JP5.2, U1.5 (P0.04)
VCC: D18.3 (VDD), D23.3 (VDD), D24.3 (VDD), JP2.2, JP7.2, U1.10 (3V3)
row0: D1.1 (K), D2.1 (K), D3.1 (K), D4.1 (K), D5.1 (K), U1.1 (P0.02)
row1: D6.1 (K), D7.1 (K), D8.1 (K), D9.1 (K), D10.1 (K), D11.1 (K), U1.2 (P0.03)
row2: D12.1 (K), D13.1 (K), D14.1 (K), D15.1 (K), D16.1 (K), D17.1 (K), U1.3 (P0.28)
row3: D19.1 (K), D20.1 (K), D21.1 (K), D22.1 (K), U1.4 (P0.29)

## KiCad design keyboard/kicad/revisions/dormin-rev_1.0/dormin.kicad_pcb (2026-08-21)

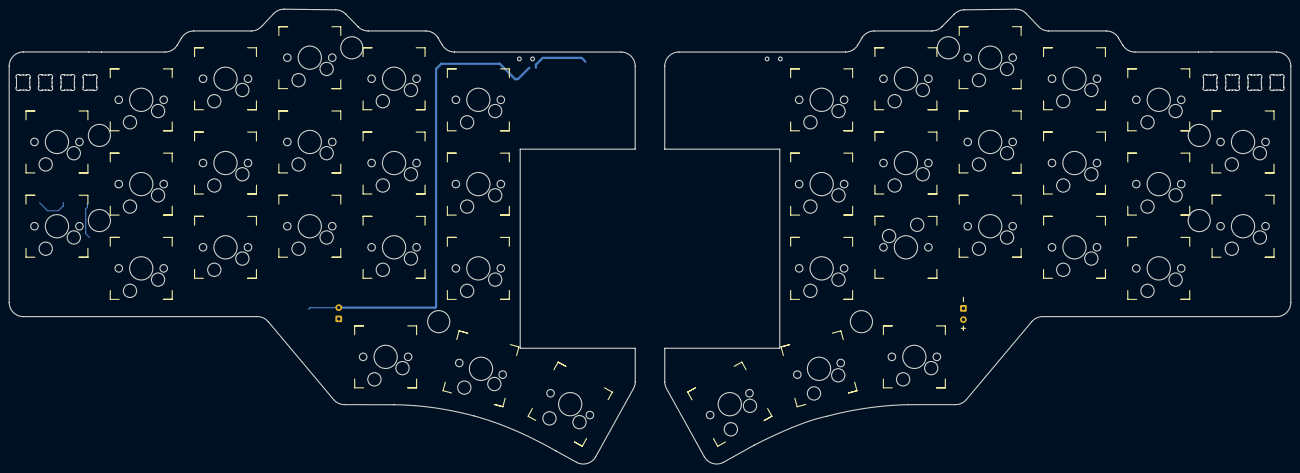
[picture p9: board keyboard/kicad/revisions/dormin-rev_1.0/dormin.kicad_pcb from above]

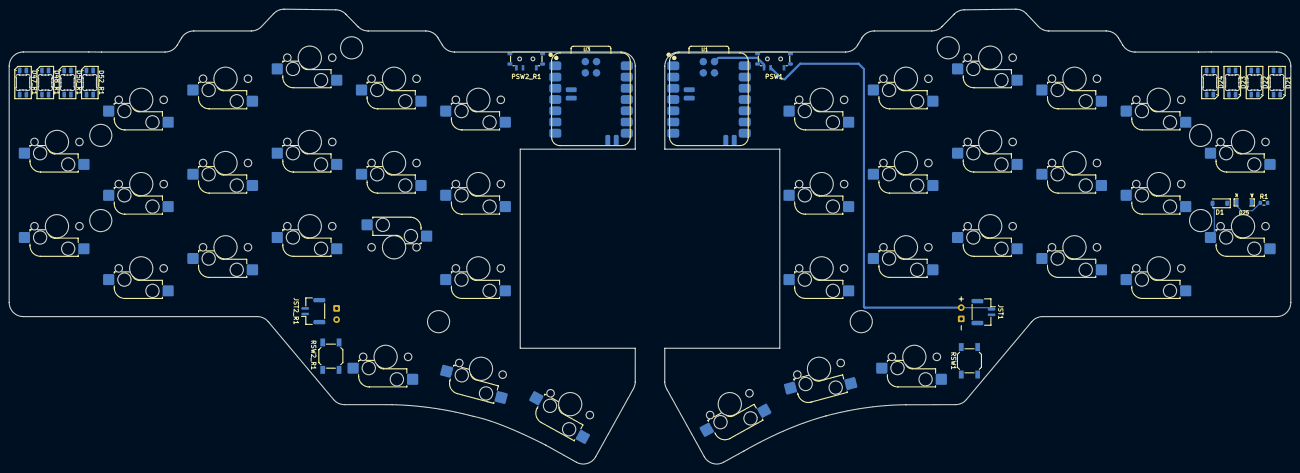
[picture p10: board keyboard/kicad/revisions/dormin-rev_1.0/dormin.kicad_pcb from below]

Board: 2 copper layers, 289.7 x 102.8 mm, 61 parts (20 on the bottom side), 31 nets.

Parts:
BT1, BT2_R1: Pads; Battery_Pad
D1: 1N4148W; D_SOD-123
D21, D22, D23, D24, D47_R1, D48_R1, D50_R1, D52_R1: SK6812MINI-E; LED_SK6812MINI-E_3.2x2.8mm_P1.5mm_ReverseMount
D25: LED; LED_MHT151WDT
JST1, JST2_R1: Conn_01x02_Pin; JST_GH_SM02B-GHS-TB_1x02-1MP_P1.25mm_Horizontal
PSW1, PSW2_R1: SW_SPDT; SW_MSK12C02-HB
R1: 1K; R_0603_1608Metric
RSW1, RSW2_R1: RSW1; SW_SPST_SKQG_WithStem
SW1, SW2, SW3, SW4, SW5, SW6, SW7, SW8, SW9, SW10, SW11, SW12, SW13, SW14, SW15, SW16, SW17, SW18, SW19, SW20, SW21, SW22, SW23, SW24, SW25, SW26, SW27, SW28, SW29, SW30, SW31, SW32, SW33, SW34, SW35, SW36, SW37, SW38, SW39, SW40: SW_Push; NF_LED_1206_SW_KS33_3_0_HS_1U
U1, U3: XIAO-nRF52840-SMD

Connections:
COL0: SW1.2, SW2.2, U3.5 (D4)
COL0_R: SW35.2, SW36.2, SW37.2, SW38.2, U1.5 (D4)
COL1: SW3.2, SW4.2, SW5.2, U3.6 (D5)
COL1_R: SW32.2, SW33.2, SW34.2, SW39.2, U1.6 (D5)
COL2: SW6.2, SW7.2, SW8.2, U3.7 (D6)
COL2_R: SW29.2, SW30.2, SW31.2, SW40.2, U1.7 (D6)
COL3: SW9.2, SW10.2, SW11.2, SW18.2, U3.8 (D7)
COL3_R: SW26.2, SW27.2, SW28.2, U1.8 (D7)
COL4: SW12.2, SW13.2, SW14.2, SW19.2, U3.9 (D8)
COL4_R: SW23.2, SW24.2, SW25.2, U1.9 (D8)
COL5: SW15.2, SW16.2, SW17.2, SW20.2, U3.10 (D9)
COL5_R: SW21.2, SW22.2, U1.10 (D9)
GND: BT1.2 (-), D21.1 (VSS), D22.1 (VSS), D23.1 (VSS), D24.1 (VSS), JST1.2, RSW1.2, U3.13 (GND), U3.18 (GND), U3.20 (GND)
GND_R: BT2_R1.2 (-), D47_R1.1 (VSS), D48_R1.1 (VSS), D50_R1.1 (VSS), D52_R1.1 (VSS), JST2_R1.2, RSW2_R1.2, U1.13 (GND), U1.18 (GND), U1.20 (GND)
unnamed: D1.2 (A), SW1.1
unnamed: D21.4 (DOUT), D22.2 (DIN)
unnamed: D21.3 (VDD), D22.3 (VDD), D23.3 (VDD), D24.3 (VDD)
unnamed: D22.4 (DOUT), D23.2 (DIN)
unnamed: D23.4 (DOUT), D24.2 (DIN)
unnamed: D25.1 (K), R1.1
unnamed: D47_R1.4 (DOUT), D48_R1.2 (DIN)
unnamed: D47_R1.3 (VDD), D48_R1.3 (VDD), D50_R1.3 (VDD), D52_R1.3 (VDD)
unnamed: D48_R1.4 (DOUT), D50_R1.2 (DIN)
unnamed: D50_R1.4 (DOUT), D52_R1.2 (DIN)
RESET: RSW1.1, U3.17 (EN)
RESET_R: RSW2_R1.1, U1.17 (EN)
ROW2: D1.1 (K), U3.3 (D2)
VBAT: D25.2 (A), PSW1.3 (C), U3.19 (VBAT)
VBAT_R: PSW2_R1.3 (C), U1.19 (VBAT)
VBAT_RAW: BT1.1 (+), JST1.1, PSW1.2 (B)
VBAT_RAW_R: BT2_R1.1 (+), JST2_R1.1, PSW2_R1.2 (B)

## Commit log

2026-07-19 feat: improved ergogen layout and features specs
    [dormin_v1.dxf, dormin_v1.kicad_pcb, dormin_v1.kicad_sch]
2026-07-21 refactor: added initial versions of the pcb
    [dormin-rev_1.0.kicad_pcb, dormin-rev_1.0.kicad_sch, dormin_v1.dxf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]
2026-07-21 chore: added ergogen pcb test
2026-07-22 refactor: update pcb
    [dormin-rev_1.0.kicad_sch]
2026-07-27 feat: update ergogen and kicad
    [dormin-rev_1.0.kicad_pcb, dormin-rev_1.0.kicad_sch, dormin_v1.dxf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]
2026-07-27 fix(ergogen): update thumb spread and generate switches for both halves
    [dormin.kicad_pcb, dormin.kicad_sch, right.kicad_sch]
2026-07-27 feat: improve margin for pcb and case
2026-07-28 feat: update schematics
    [dormin.kicad_sch]
2026-07-29 feat: added dormin outline
    [ble_plate.kicad_pcb, border_outline.kicad_pcb, border_outline_raw.kicad_pcb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]
2026-07-30 feat: fix pcb outline
    [border_outline.kicad_pcb, dormin.kicad_pcb, dormin_pcb_outlines.kicad_pcb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]
2026-07-30 feat: refine PCB outline
    [dormin.kicad_pcb]
2026-07-31 feat: clean pcb and outline
    [dormin.kicad_pcb, dormin.kicad_sch]
2026-07-31 feat: start PCB placement
    [dormin.kicad_pcb, dormin.kicad_sch]
2026-08-01 feat: added pogo-pin pcb components
    [dormin.kicad_pcb, dormin.kicad_sch]
2026-08-02 feat: added support for white backlight (wip)
    [dormin.kicad_pcb, dormin.kicad_sch]
2026-08-02 feat: organize schematics sheet
    [dormin.kicad_sch]
2026-08-02 feat: added 4-pin extension support
    [dormin.kicad_sch]
2026-08-03 feat: organize backlight components
    [dormin.kicad_pcb]
2026-08-04 feat: added 3dmodels and improve components placement
    [dormin.kicad_pcb, dormin.kicad_sch]
2026-08-05 feat: updated schematics
    [dormin.kicad_pcb, dormin.kicad_sch]
2026-08-06 feat: organize pcb components placements
    [dormin.kicad_pcb, dormin.kicad_sch]
2026-08-07 feat: implemented better status-led-system
    [dormin.kicad_sch]
2026-08-07 feat: improve schematics and pcb components placements
    [dormin.kicad_pcb, dormin.kicad_sch]
2026-08-09 feat: improve schematics and components placement
    [dormin.kicad_pcb, dormin.kicad_sch]
2026-08-09 chore: added right sheet schematics
    [dormin.kicad_pcb, dormin.kicad_sch, dormin_left.kicad_sch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]
2026-08-09 chore: update reference names for the right schematic
    [dormin.kicad_pcb, dormin_right.kicad_sch]
2026-08-09 chore: added panelized boards
    [dormin.kicad_pcb, dormin_original.kicad_pcb, dormin_pcb_outlines.kicad_sch]
2026-08-09 feat: added mouse bites and organize files
    [ble_plate.kicad_pcb, border_outline.kicad_pcb, border_outline_raw.kicad_pcb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]
2026-08-09 feat: updated pogo-pin schematics
    [dormin_left.kicad_sch, dormin_right.kicad_sch]
2026-08-10 feat: added initial components to the right places
    [dormin.kicad_pcb, dormin_left.kicad_sch, dormin_right.kicad_sch]
2026-08-10 feat: placed components for the left half
    [dormin.kicad_pcb]
2026-08-10 feat: finish pcbs component placements
    [dormin.kicad_pcb]
2026-08-10 feat: adjust schematics for the switches logic order
    [dormin.kicad_pcb, dormin_left.kicad_sch, dormin_right.kicad_sch]
2026-08-14 feat: added routing to the left pcb
    [dormin.kicad_pcb, dormin_left.kicad_sch, dormin_right.kicad_sch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]
2026-08-14 feat: improved ergogen config and exported pcb
    [dormin.kicad_pcb, dormin_u_col.kicad_pcb]
2026-08-15 feat: added new pcb design
    [dormin.kicad_pcb, dormin_left.kicad_sch, dormin_right.kicad_sch]
2026-08-17 feat: added batteries and standoffs cutouts
    [dormin.kicad_pcb]
2026-08-17 feat: remove unused components for v1
    [dormin.kicad_pcb, dormin.kicad_sch, dormin_left.kicad_sch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]
2026-08-17 refactor: fix xiao footprint and symbol
    [dormin.kicad_pcb, dormin_left.kicad_sch, dormin_right.kicad_sch]
2026-08-18 refactor: added screw boss markes
    [dormin.kicad_pcb]
2026-08-19 feat: added .dxf file for the case
    [dormin_case_v1.dxf]
2026-08-19 feat: added outline borders to the case sketch
    [dormin_case_v1.dxf]
2026-08-20 refactor: improved sketch outlines and add magnets drawing
    [dormin_case_v1.dxf]
2026-08-21 feat: added keyboard logo to the case
    [case_sketch.dxf, dormin.kicad_pcb, dormin_case_v1.dxf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]
